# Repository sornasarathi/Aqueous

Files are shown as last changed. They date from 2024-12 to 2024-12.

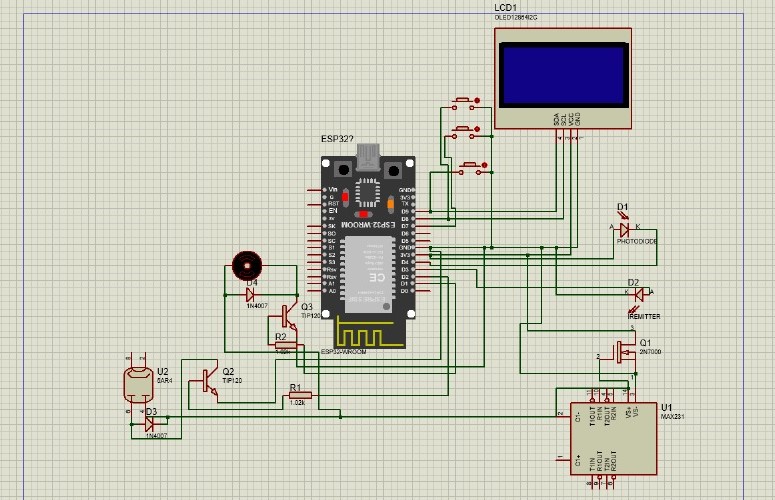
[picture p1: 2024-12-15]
PROTEUS.jpg

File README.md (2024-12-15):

# Aqueous

## The Tono_LITE 
This is a portable, cost-effective, non-contact device for at-home intraocular pressure (IOP)
measurement in glaucoma patients, addressing the limitations of traditional high-cost, contact-based tools.
It uses an air puff unit with a pump, regulator, solenoid valve, and nozzle to generate and control air
pressure for corneal applanation, ranging from 600 mmHg to 50 mmHg, guided by Bernoulli’s principle. An
880 nm IR emitter and a photodiode (sensitive to 700-1100 nm) detect corneal flattening, with the
photodiode’s nanosecond response capturing fine changes. The ESP32 microcontroller manages the air puff
and processes IR data, supporting IoT-based remote patient monitoring. Results are displayed on an OLED
screen, and data is transmitted securely to a cloud platform. The device employs an advanced tonometry
algorithm, correcting for corneal hysteresis and central corneal thickness (CCT) to ensure accurate readings,
even after corneal surgeries. Weighing 750g and built with ISO-certified medical components, the TonoLITE
offers a user-friendly, precise, and reliable tool for proactive glaucoma management at home.

YouTube : https://youtu.be/uMQLXOlUx8E?si=PbhPJDeiQuzWr4GM

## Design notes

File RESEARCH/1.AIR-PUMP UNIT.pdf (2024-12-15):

# AIR-PUMP UNIT

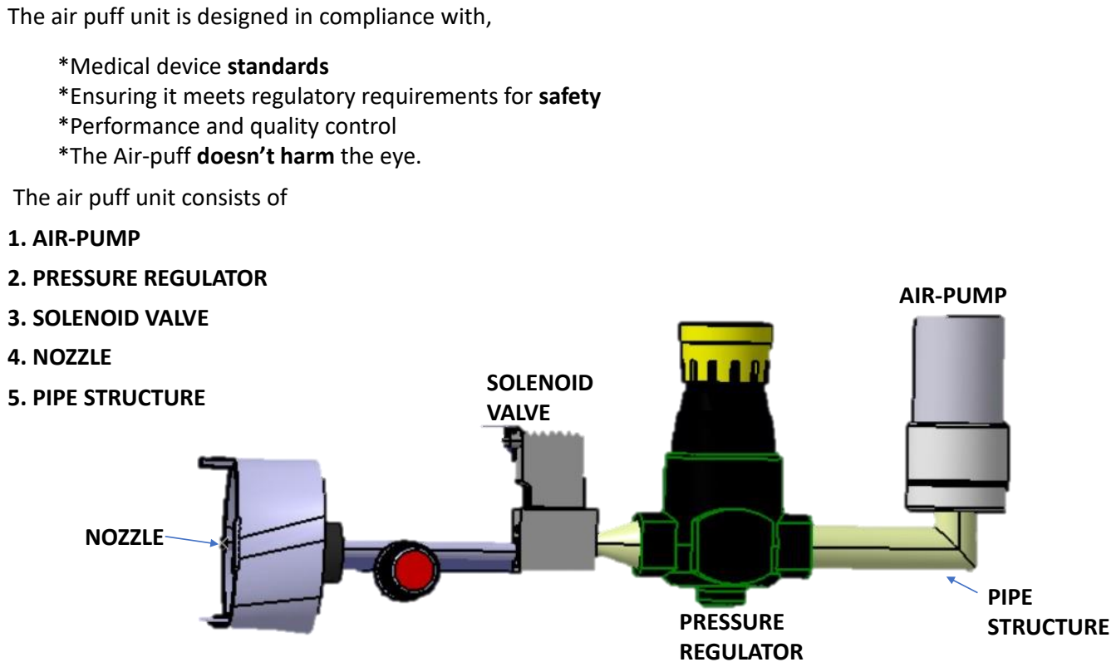
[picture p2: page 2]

The air puff unit is designed in compliance with,

*Medical device standards
*Ensuring it meets regulatory requirements for safety *Performance and quality control
*The Air-puff doesn’t harm the eye.
The air puff unit consists of

### 1. AIR-PUMP 2. PRESSURE REGULATOR

### 3. SOLENOID VALVE 4. NOZZLE

### 5. PIPE STRUCTURE

AIR-PUMP

PRESSURE
REGULATOR

SOLENOID
VALVE

NOZZLE

PIPE
STRUCTURE

To generate the required puff of air ,a 12V DC vacuum air pump will be used.

*Rated current = 300mA
*Air pump rate = 4LPM
* Maximum pressure = 750mmHg
*Operation will be controlled by a push button and the ESP32 *It has a length of 68mm and a diameter of 24mm,small in size

### 1. AIR-PUMP:

### 2. PRESSURE REGULATOR:

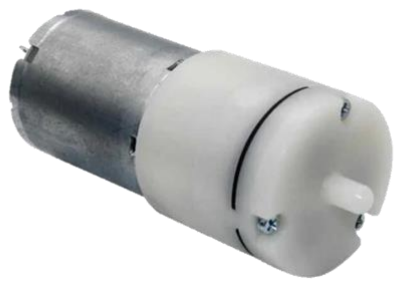
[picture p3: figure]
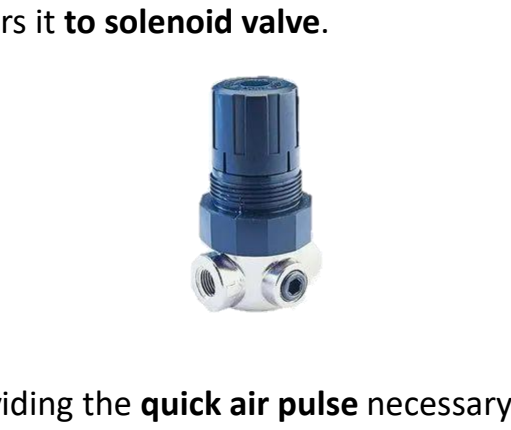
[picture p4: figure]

It regulates the pressure coming from the air pump and delivers it to solenoid valve.

*Miniature air pressure regulator series
*Ensures air puff is strong enough to flatten the cornea
*Maximum supply pressure = 17.2 bar | (12901.06mmHg)
*Can regulate up to desired air pressure | (50-55 mmHg)
*Regulate up to 0-4.1bar

### 3. SOLENOID VALVE:

The solenoid valve opens and closes within milliseconds, providing the quick air pulse necessary for accurate tonometry.
The solenoid valve controls the release of a precise and rapid air puff directed toward the eye for IOP measurement.

*Flow model = unidirectional *Response time-less than 50ms *Operating pressure = 1.2Mpa *Flow rate = 0.23Cv(fluid flow)
*Valve type-2 way normally open

### 4. NOZZLE:

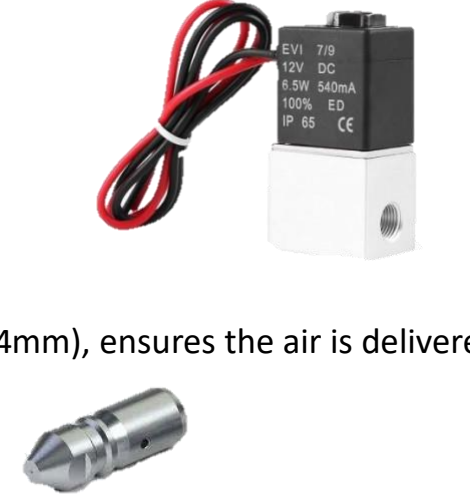
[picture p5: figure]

It focuses air puff towards Center of the cornea (3-4mm), ensures the air is delivered in precise.

*Customized 3D printed ROUND-JET model
*Diameter = 2mm
*Length = 2cm

From this Nozzle ,we can ensure that delivered air-pressure will be 55mmHg.

### 5. PIPE STRUCTURE:

Ensuring a smooth flow of air within the system ,without significant loss of pressure.
Designed to maintain consistent pressure and velocity profiles for optimal performance in the air puff mechanism.

*The pipe structure follows BERNOULLI’S PRINCIPLE TO AVOID PRESSURE LOSS.
*Material used in the construction of pipe is Polyurethane (PU).

Finally by calibrating all the units output ,we can get controlled output (55mmhg) to measure the IOP accurately without harming the user.

For orientation of cornea : Neon glittering paint is coated in the outer rim of nozzle , to achieve the correct orientation, X shaped mark is made in the hollow part of nozzle, so that the IR emitter and photodiode which are present in the sides of nozzle can align correctly.

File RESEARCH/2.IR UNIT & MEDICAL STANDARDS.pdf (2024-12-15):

# IR UNIT & MEDICAL STANDARDS (IEC-60825-1 & ANSI Z136.1)

## Ocular Response Analyzer:

The Ocular Response Analyzer (ORA) is a non-contact device used to measure INTRAOCULAR PRESSURE (IOP) and BIOMECHANICAL PROPERTIES of the cornea.

Unlike traditional tonometry methods (e.g., Goldmann applanation tonometry), which primarily measure IOP based on corneal flattening, the ORA offers a more comprehensive analysis by considering the corneal biomechanics.

How it Differs from an Air-puff Tonometer?
The air-puff tonometer measures IOP by using a puff of air to flatten (applanate) the cornea. The device detects the force or timing at which the cornea flattens, and from this, it calculates the intraocular pressure.It only uses one applanation event (the point where the cornea flattens due to the air puff) to calculate IOP.

The ORA uses an air puff to flatten the cornea, measuring two applanation events: one during inward movement and another as the cornea returns to its original shape. It calculates corneal hysteresis (CH)—the cornea’s ability to absorb and dissipate energy—by analyzing the difference between these points. It also provides two IOP measurements: Goldmann-correlated IOP (IOPg) and corneal-compensated IOP (IOPcc).

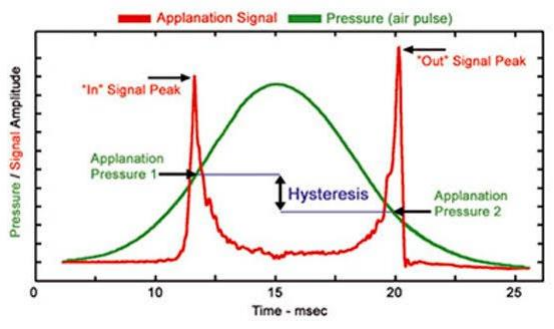
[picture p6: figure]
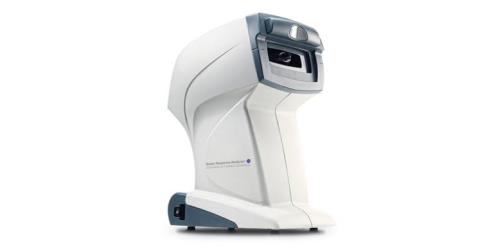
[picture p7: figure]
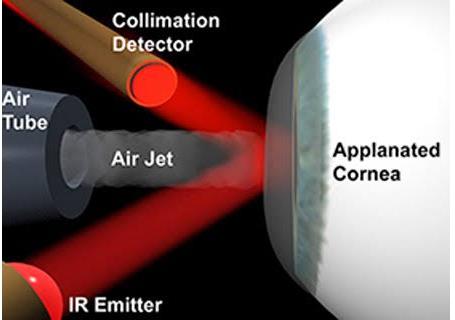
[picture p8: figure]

ORA | Applanation | corneal hysteresis

Feature | Air-puff Tonometer | Ocular Response Analyzer (ORA)
Primary Measurement | IOP | IOP (IOPg and IOPcc) + Corneal Hysteresis
Applanation Events | Single Applanation | Dual Applanation (Inward & Outward)
Corneal Compensation | No | Yes (IOPcc accounts for corneal properties)
Biomechanical Measurement | No | Yes (Corneal Hysteresis - CH)
Use Cases | Routine IOP Screening | Glaucoma Management, Corneal Biomechanics
Corneal Abnormality Accuracy | Less accurate | More accurate due to IOPcc and CH
Non-Contact | Yes | Yes

We have choose the method of Ocular Response Analyzer ,which can be achieved in a Miniature model with High accuracy
So,
It requires a Reliable IR unit ,which should adapt with the Medical Standards because it will be directly used on the Eye and should be highly faster in terms of Measurements.

INFRARED-EMITTER:

Why Infrared light?
In the Electromagnetic Spectrum range of Near Infrared (700 to 1400 nm) can penetrate the cornea deeply and efficiently, minimizes light scattering, provides clear signal detection, and enhances patient comfort by being non-visible. The use of NIR light allows for accurate, non-invasive, and reliable measurements of IOP and corneal biomechanics, such as corneal hysteresis (CH), making it an optimal choice for this device.

Specs of IR emitter ,we have choose for Our Tono_Lite:

Feature | IR-LED
Wavelength | 860 nm
Radiant Intensity | 500 mW/sr
Beam Angle | 6 degree
Rise & Fall Time | 12ns
Mounting Style | Through Hole

*Fastest IR Emitter (12ns)
* 860nm is ideally used in Air-puff tonometer and ORA ,due to better reflection by cornea.
*IR needs to focus on the center of the cornea (11mm) to get the accurate Results ,So the IR beam we have choose (6 deg) covers 2.17<11mm ,which can accurately Emit the IR wave to the center of the cornea.

How it Meets the Medical Standards Guidelines ? Irradiance :
Irradiance refers to the power of electromagnetic radiation (like light) per unit area incident on a surface, typically measured in watts per square meter (W/m²). In the context of an IR (infrared) emitter, irradiance measures how much infrared energy (in terms of power) hits a specific area.
Irradiance (E) Calculation for the specified IR emitter:

## E=I/d^2

Where:
E = irradiance (mW/cm²)
I = radiant intensity (mW/sr) (500mW/sr)
d = distance from the emitter in centimeters (cm) (d=2.5) So,
Calculated E= 84.22mW/cm^2.
Medical Standard (IEC-60825-1 & ANSI Z136.1) :
*IEC-60825-1 & ANSI Z136.1 :
It is the Medical Guideline should be followed to ensure eye safety when the exposure Light is IR laser (narrow beam)

Maximum Exposure Time (t) =(Irradiance/(MPE coefficient×C4×C6))^1.33 Irradiance = 84.22mW/cm^2
MPE coefficient = 2.7×10^4
C6=1
C4=3.16 (above all ideal for Wavelength of 860nm from the guidelines)

By substituting all the values,
Finally ,MPE (t) = 42 ms

Time taken by the Total applanation and rebound time is 20 to 25 ms
(The Maximum Permissible Exposure time is more than enough for our application)

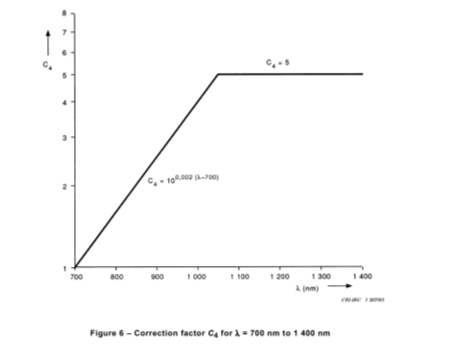
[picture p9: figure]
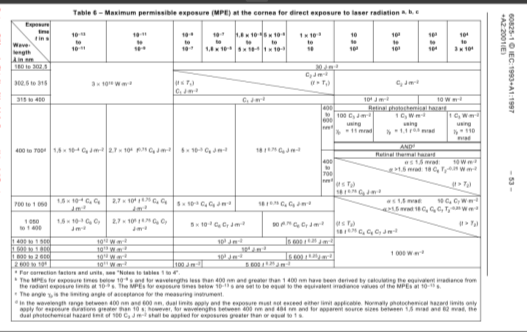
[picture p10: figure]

MPE | Correction Factor

Finally ,We can conclude that ,the IR Emitter is the best fit our application. <if anything after evaluation doesn’t fit with medical conditions ,it will overhauled>

*Before the air-puff Reflected output from the Cornea’s convex shape is broader.
*After the puff from the puff unit ,cornea applanates and reflects the emitted IR waves narrow.

*The reflected IR wave will be 2-5% (1.6868-4.217 mW/cm^2) in the emitted signal ,we can significantly detect the reflected wave from when the emitter and sensor are 30-45 degree placed to the eye’s central part
*To detect the reflected low power IR wave ,we require a robust sensor

Photo-Diode:

Feature | Photodiode
Wavelength | 320 to 1100 nm
Type | Si-PIN
Photosensitivity | 0.72 A/W
Response Time | 0.5ns
Mounting Style | SMT
Dark-Current | 10000 pA
Photo-sense Area | 11 × 6 mm

Least Irradiance
Detection | 0.0417 mW/cm²

Ta=25 ℃, Typ., Photosensitivity: λ=λp, Dark current: VR==10 V, Cutoff frequency: VR=10 V, Terminal capacitance: VR=10 V, f=1 MHz, Noise equivalent power: VR=10 V, λ=λp, unless otherwise noted

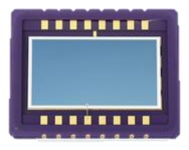
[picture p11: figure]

Due to its High Sensitive and Rapid Response Time ,it will be ideal for our application

Finally with the corneal hysteresis analysis and CCT value ,Controller unit determines the IOP without any miscalculation.

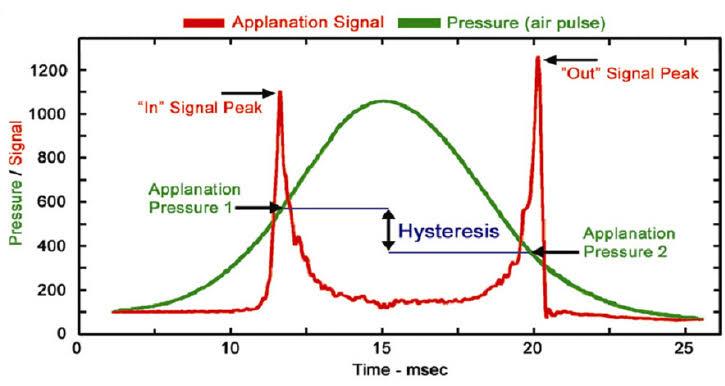
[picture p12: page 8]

corneal hysteresis

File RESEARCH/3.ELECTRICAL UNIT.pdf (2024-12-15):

# ELECTRICAL UNIT

•

## - The electrical unit plays a crucial role in controlling and managing the device’s components, ensuring accurate and

reliable intraocular pressure (IOP) measurement.

## - It consists of 1.Power supply 2.Controller 3.Display 4.Transistor 5.Mosfet 6.Buttons

POWER SUPPLY:
Rechargeable lithium-ion battery
- Output voltage - 12v
- Capacity -1200mAH
- Time taken to charge - 24 minutes.
- Battery life - 1 hour 30 minutes
- Dimensions - 6.8 x 5.5 x 2 cm
- | Weight | - 150g

CONTROLLER:
ESP32 WROOM
- Type - ESP-32 with Wi-Fi 802.11 b/g/n
- Operating voltage - 5V.
- Output voltage - 3.3-5V.
- Dimensions - 5 x 2.8 x 1.5 cm
- | Weight | - 80g

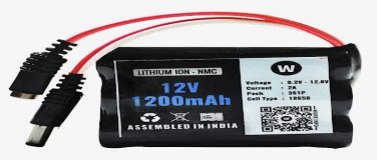
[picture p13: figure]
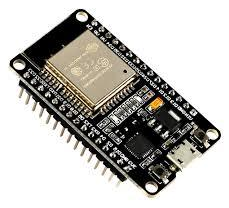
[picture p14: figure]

ESP32 will be responsible for controlling the logic for the air pump, solenoid valve, IR emitter, and reading data from the photodiode.

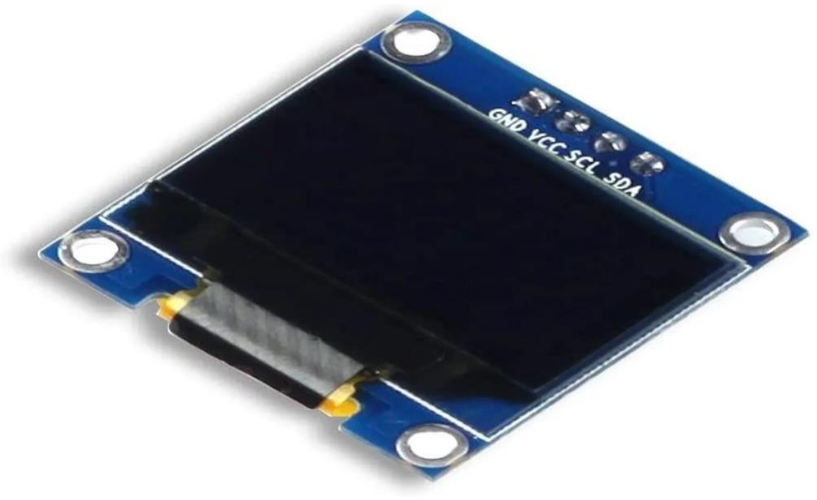
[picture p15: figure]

DISPLAY:
- Type - OLED Module
- Protocol - I2C
- | Support Voltage | : 3.3 | - 5V.
- | Viewing angle - | >160°
- | Dimensions - | 27mm x 27mm x 4mm
- | Weight | - 10g

Delivers a better view of output to the user.

TRANSISTOR:

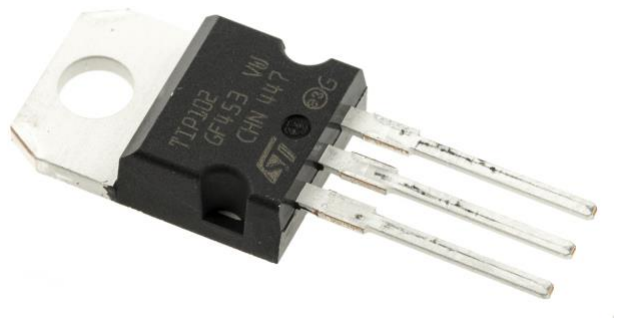
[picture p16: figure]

- It is used for switching and amplification purpose
- Switching: Control solenoid valves for air release
- Amplification: Boost weak sensor signals for better processing
- Control: Enable precise regulation of components like air pumps
- Using TIP102 transistor

### 5.MOSFET:

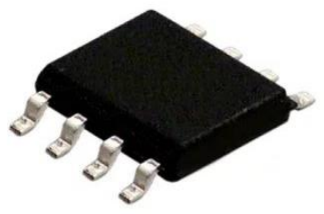
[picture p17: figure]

## - The purpose of the MOSFET in this design is mainly related to power management, switching, and precise control of the electrical components

such as the solenoid valve, air pump, or sensor circuitry.

## - Using MP1584 MOSFET

### 6.BUTTONS :

- It consists of Power button and Push button Medical-Grade Plastics:
ABS (Acrylonitrile Butadiene Styrene):

Properties: Durable, impact-resistant, and relatively lightweight.

Advantages: Easily molded into different shapes, cost-effective, and used in medical devices.

Applications: Commonly used in enclosures for medical instruments due to its strength and ease of processing.

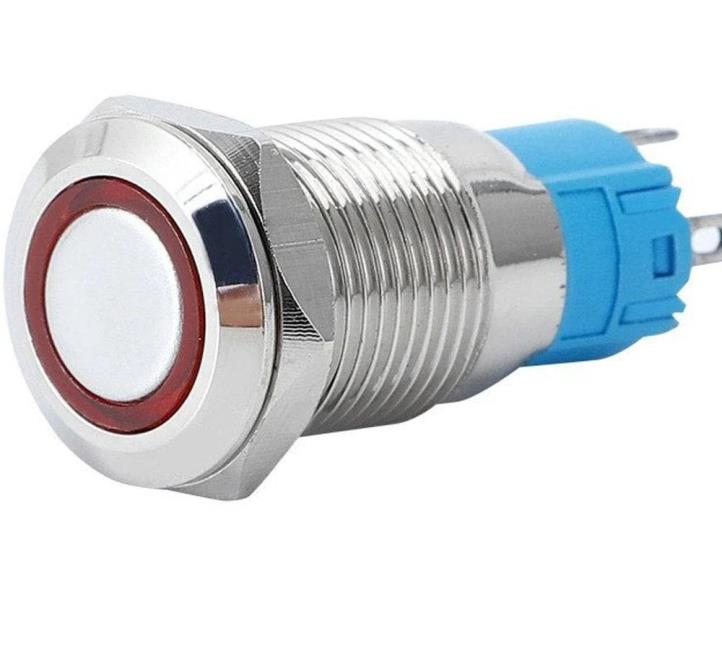
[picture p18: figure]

## Power button:

## - It is used for on /off purpose to perform the operation

- Operating voltage:12V DC
- Operating current:2A MAX
- It is of 12mm
- It is used to on the device and for releasing of air puff

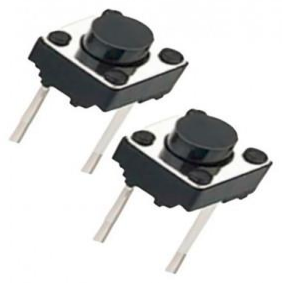
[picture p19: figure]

### Push button: - It is used for adjusting the value of CCT - It uses 2 push buttons of 5mm

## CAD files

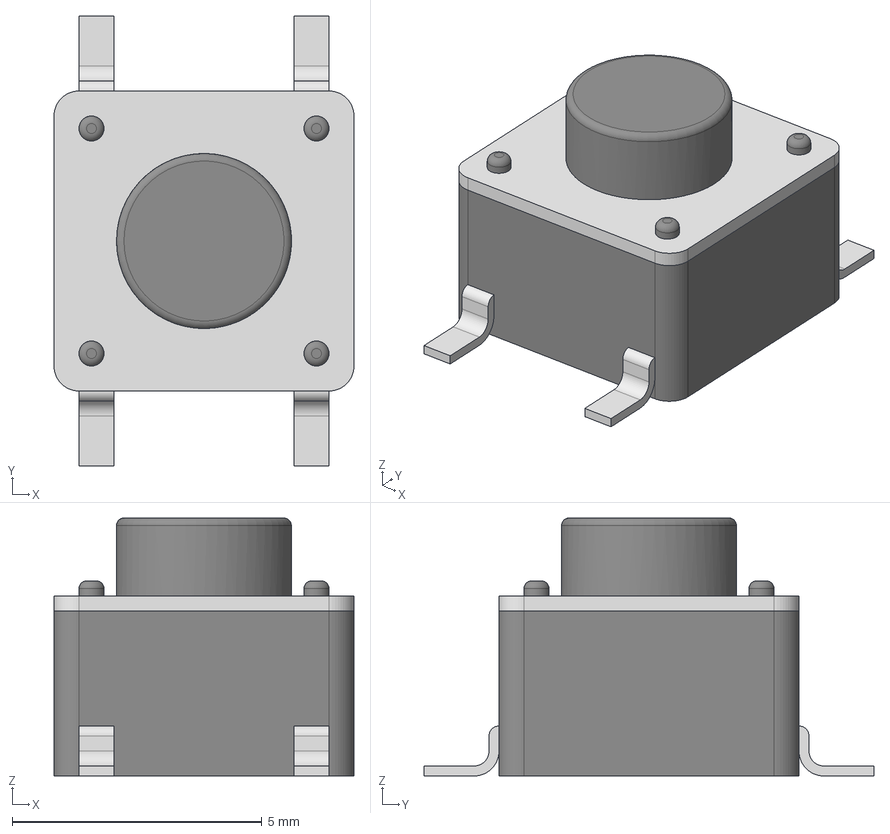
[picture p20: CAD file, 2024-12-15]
DEVICE-CATIA_MODEL/Small_pushbutton_pad.stp
6.00 x 9.00 x 5.16 mm
Button_body
Button_plate
Button_pad x 4

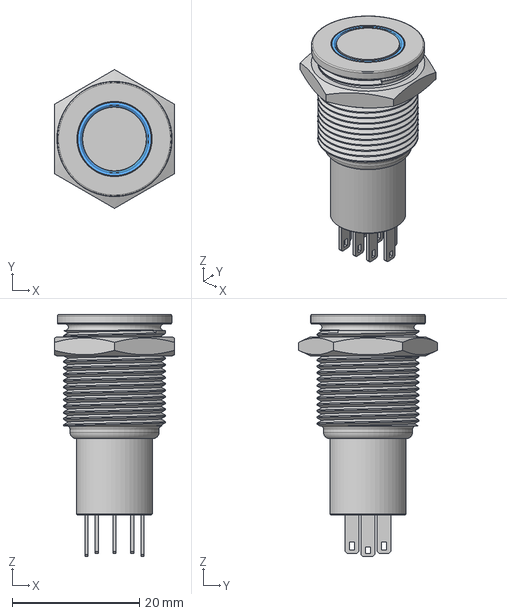
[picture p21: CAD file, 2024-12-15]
DEVICE-CATIA_MODEL/Illuminated button LAS2GQ-F22-EB-24.stp
18.9 x 21.8 x 38.0 mm

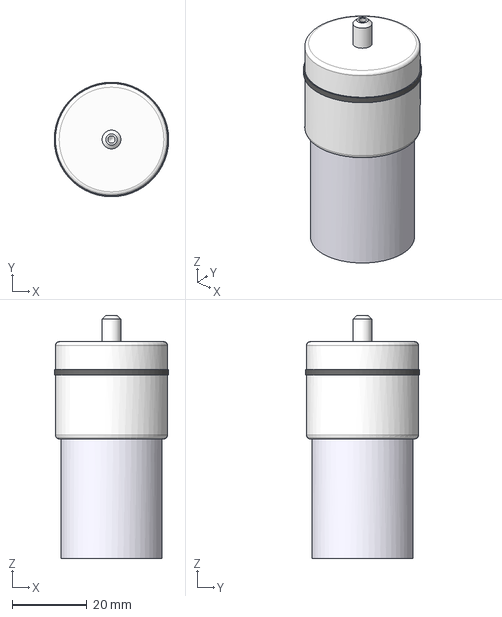
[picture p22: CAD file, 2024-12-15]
DEVICE-CATIA_MODEL/Pump motor.stp
30.6 x 30.6 x 65.0 mm

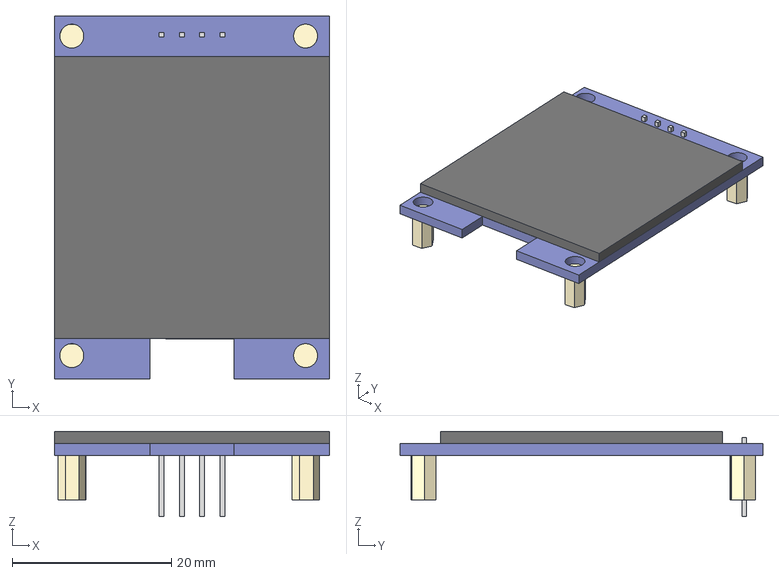
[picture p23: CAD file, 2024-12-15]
DEVICE-CATIA_MODEL/oledscreen.step
34.5 x 45.5 x 10.7 mm
Bileşen1
Bileşen2

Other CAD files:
DEVICE-CATIA_MODEL/3D_ESP32DEVKITV4_2024-06-01.CATProduct
DEVICE-CATIA_MODEL/8.09.2023_19_54_1.CATPart
DEVICE-CATIA_MODEL/Battery Pack 1200mAh - Copy.CATPart
DEVICE-CATIA_MODEL/Board.CATPart
DEVICE-CATIA_MODEL/Button_body.CATPart
DEVICE-CATIA_MODEL/Button_pad.CATPart
DEVICE-CATIA_MODEL/Button_plate.CATPart
DEVICE-CATIA_MODEL/COMPOUND.CATPart
DEVICE-CATIA_MODEL/COMPOUND_1.CATPart
DEVICE-CATIA_MODEL/COMPOUND_2.CATPart
DEVICE-CATIA_MODEL/COMPOUND_3.CATPart
DEVICE-CATIA_MODEL/COMPOUND_4.CATPart
DEVICE-CATIA_MODEL/COMPOUND_5.CATPart
DEVICE-CATIA_MODEL/COMPOUND_6.CATPart
DEVICE-CATIA_MODEL/COMPOUND_7.CATPart
DEVICE-CATIA_MODEL/COMPOUND_8.CATPart
DEVICE-CATIA_MODEL/IR emitter.CATPart
DEVICE-CATIA_MODEL/N-730.catproduct
DEVICE-CATIA_MODEL/N-730clip.CATPart
DEVICE-CATIA_MODEL/N-730contact.CATPart
DEVICE-CATIA_MODEL/N-730cup.CATPart
DEVICE-CATIA_MODEL/N-730operator.CATPart
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
